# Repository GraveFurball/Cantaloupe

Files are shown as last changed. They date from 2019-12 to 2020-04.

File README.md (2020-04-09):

# The Cantaloupe
Yet another star configuration CAN PCB for FRC

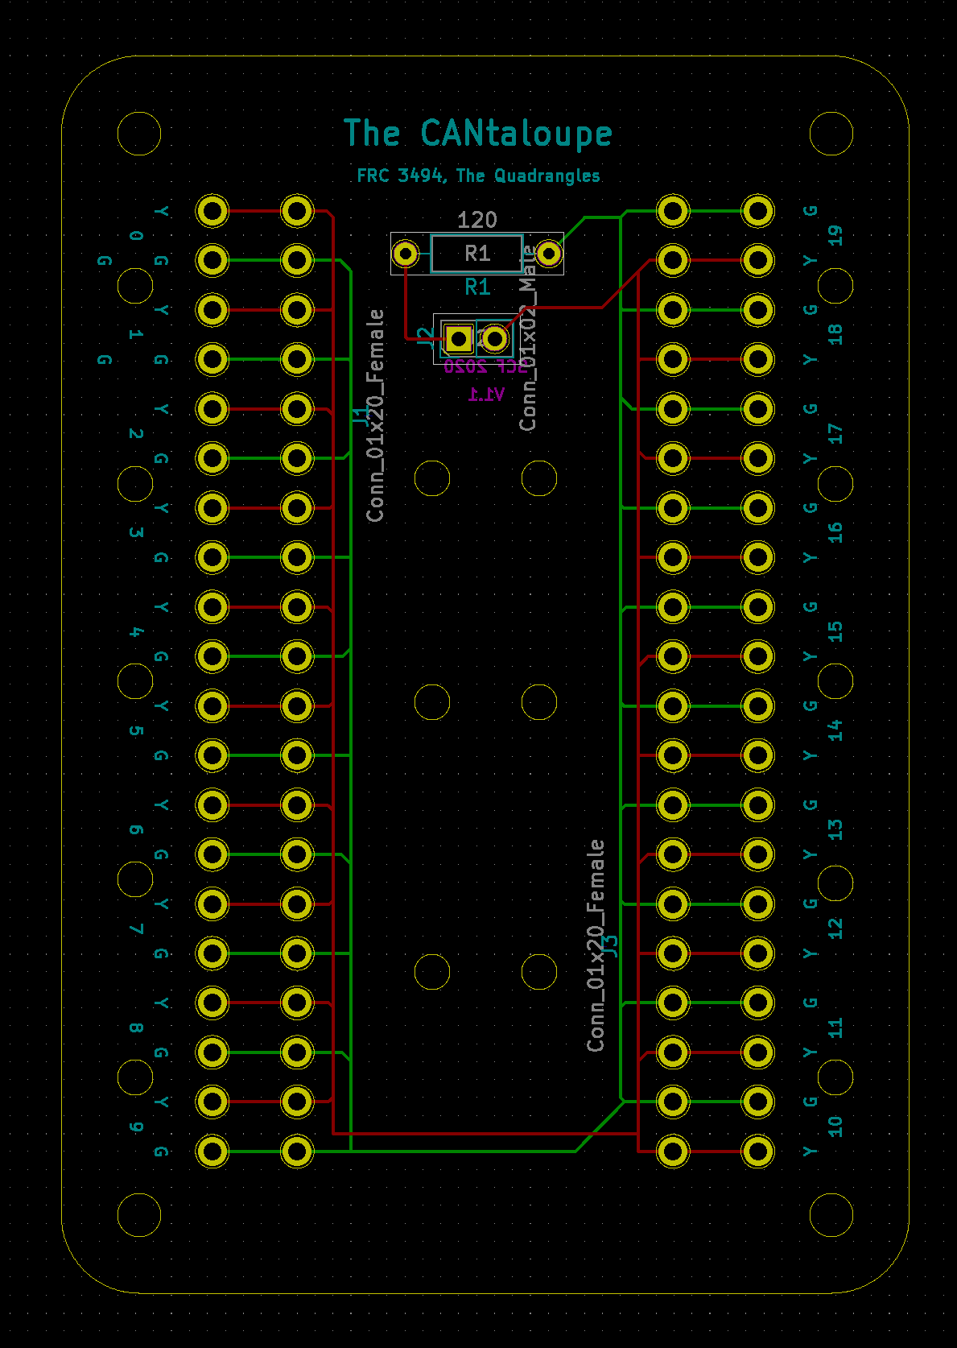
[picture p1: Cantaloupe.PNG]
Cantaloupe


The Cantaloupe is yet another PCB to enable an FRC CAN Bus to be laid out in a star topography. 
The Cantaloupe was inspired partially by FRC 6502's board, [the CANTina](https://github.com/21brownz/CANtina)
* The Cantaloupe utilizes Weidmuller LSF-SMT-3.5 push-to-connect terminal blocks to allow you to easily connect and disconnect devices.
* The Cantaloupe has the capacity for up to 20 CAN devices simultaneousely.
* The Cantaloupe has built in mounting holes for #4 screws, as well as holes intended for running zipties through to aid in cable management.
* The Cantaloupe has a built in jumper, allowing you to choose whether or not to terminate the CAN bus on the board.
* The hardware that we used to assemble the Cantaloupe is contained within the "Hardware" file.

## Warning:
Star topology can be very fussy. It violates the ISO 11898 standard and is not officially supported by any manufacturer. I do not officially condone the use of star configuration, nor do I accept any responsibility in the event that star CAN causes damage to one or more of your CAN devices. **Please be careful!**

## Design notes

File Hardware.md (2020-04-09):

https://www.digikey.com/product-detail/en/weidmuller/1870850000/281-7759-ND/4014334 **x2 IMPORTANT: If you use these connectors, make sure that the PCB is no more than 1mm thick when you order it, otherwise the pins from the connectors will not be long enough to come all the way through the board.**

https://www.digikey.com/product-detail/en/harwin-inc/M7583-05/952-2882-ND/3922851 **x1** Note: Other pin jumpers with the proper 2.54mm pitch will work as well. Just be sure that the length of your pin headers and the height of your jumper match.

https://www.digikey.com/product-detail/en/yageo/CFR-25JR-52-120R/120QTR-ND/11952 **x1** Note: Any other 6.3mm x 2.4mm 120ohm 1/4watt resistor will work as well.

https://www.digikey.com/product-detail/en/w%C3%BCrth-elektronik/61300211121/732-5315-ND/4846823 **x1** Note: Other pin headers with the proper 2.54mm pitch will work as well. Just be sure that the length of your pin headers and the height of your jumper match.

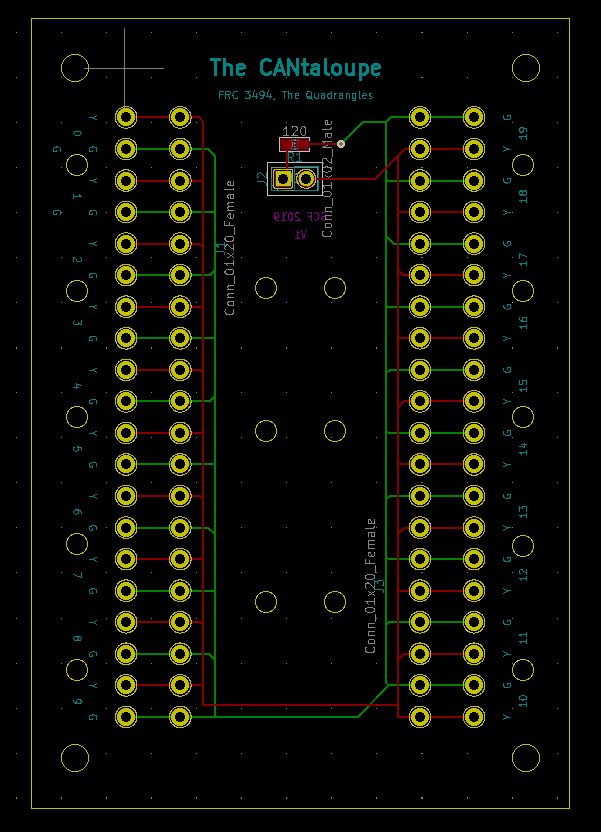
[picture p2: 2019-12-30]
Cantaloupe - Copy.PNG

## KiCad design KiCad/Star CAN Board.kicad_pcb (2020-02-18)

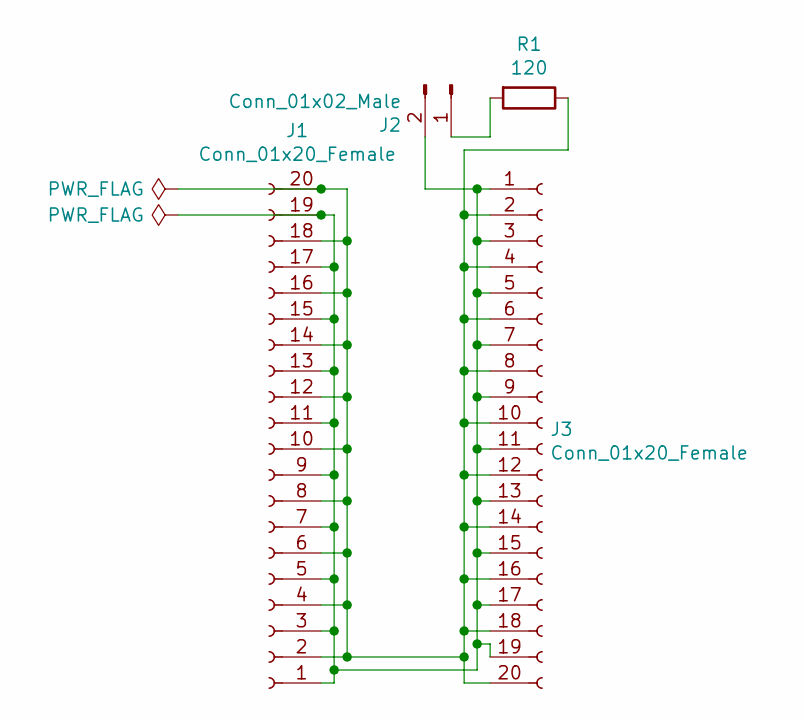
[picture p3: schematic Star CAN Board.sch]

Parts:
J1, J3: Conn_01x20_Female; Weidmuller20X1Female
J2: Conn_01x02_Male; PinHeader_1x02_P2.54mm_Vertical
R1: 120; R_Axial_DIN0207_L6.3mm_D2.5mm_P10.16mm_Horizontal

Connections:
unnamed: J1.1, J1.3, J1.5, J1.7, J1.9, J1.11, J1.13, J1.15, J1.17, J1.19, J2.2, J3.1, J3.3, J3.5, J3.7, J3.9, J3.11, J3.13, J3.15, J3.17, J3.19
unnamed: J1.2, J1.4, J1.6, J1.8, J1.10, J1.12, J1.14, J1.16, J1.18, J1.20, J3.2, J3.4, J3.6, J3.8, J3.10, J3.12, J3.14, J3.16, J3.18, J3.20, R1.1
unnamed: J2.1, R1.2

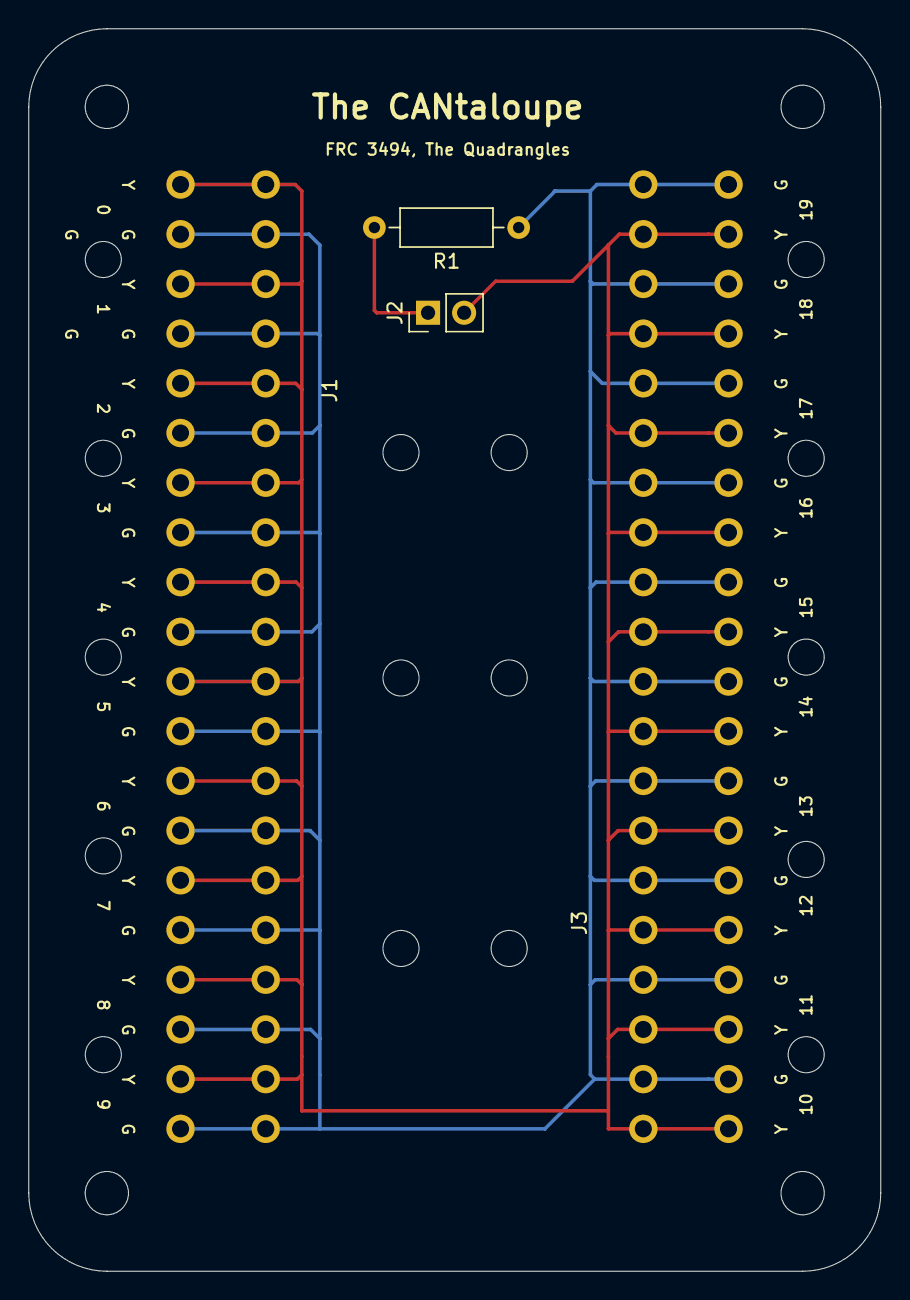
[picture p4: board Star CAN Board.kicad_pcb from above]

Board: 2 copper layers, 60.0 x 87.5 mm, 4 parts (0 on the bottom side), 3 nets.

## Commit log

2020-02-18 hi this is FizzyApple12 pushing stuff for GraveFurball ok bye
    [Star CAN Board-B_Cu.gbr, Star CAN Board-B_Mask.gbr, Star CAN Board-B_SilkS.gbr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]
2020-03-01 Removed link for old resistor
    New design uses a generic 1/4 watt through-hole resistor rather than an smd resistor, so the link is no longer useful
2020-04-09 Added a link for a resistor of the same type that we used
2020-04-09 Updated Hardware file
    Added link to pin headers, also added notes with more information about substitutes.
